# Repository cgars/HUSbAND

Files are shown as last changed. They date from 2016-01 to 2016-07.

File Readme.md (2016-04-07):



--
HUSbAND -  High freqUency StimulAtioN Device
-------------

Is a Ardoino micro based stimulation eyglass. It is used for high precission stimulation with light flickering at different frequencies.
This repsoitory contains (or will contain)
* The firmware for the arduino 
* The schemata for the eypieces and the controll board
* PCB Designs for the eypieces and the controll board

--
 Usage
-------------
The device can be used by wrtiting a command strings to the serial port emulated by the arduinos ftdi usb chip. A command consists of a upper case letter (R,G,B,I,F,H,S,X,T) and sometimes a number (R,G,B,I,F,H,T) that is either 8 bit unsigned integer (R,G,B,I) or 32 bit unsigned integer (F,H,T). Due to the way the device uses counters the Frequency the device produces will not match the frequency set exactly but it tries to come as close as possible.

Command Letter | Values | Function
------------ | -------------|-------------
R|0-1023|Red leds
G|0-1023|Green leds
B|0-1023|Blue leds
F|0-15kHZ|Frequency1
H|0-15kHz|Frequency2
T|0-99999|Time in ms between onset of freq1 and freq2
S||Start the Device
X||Stop the Device

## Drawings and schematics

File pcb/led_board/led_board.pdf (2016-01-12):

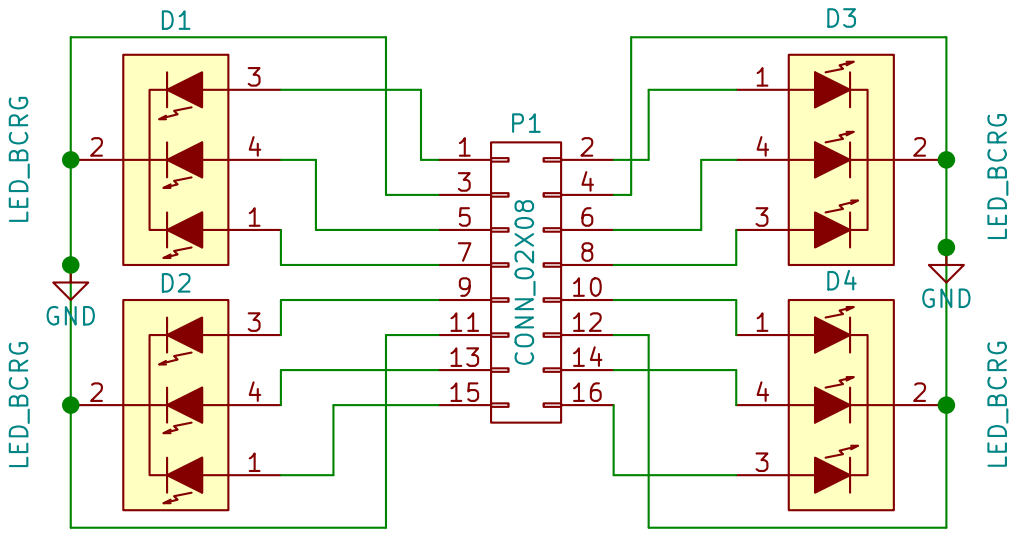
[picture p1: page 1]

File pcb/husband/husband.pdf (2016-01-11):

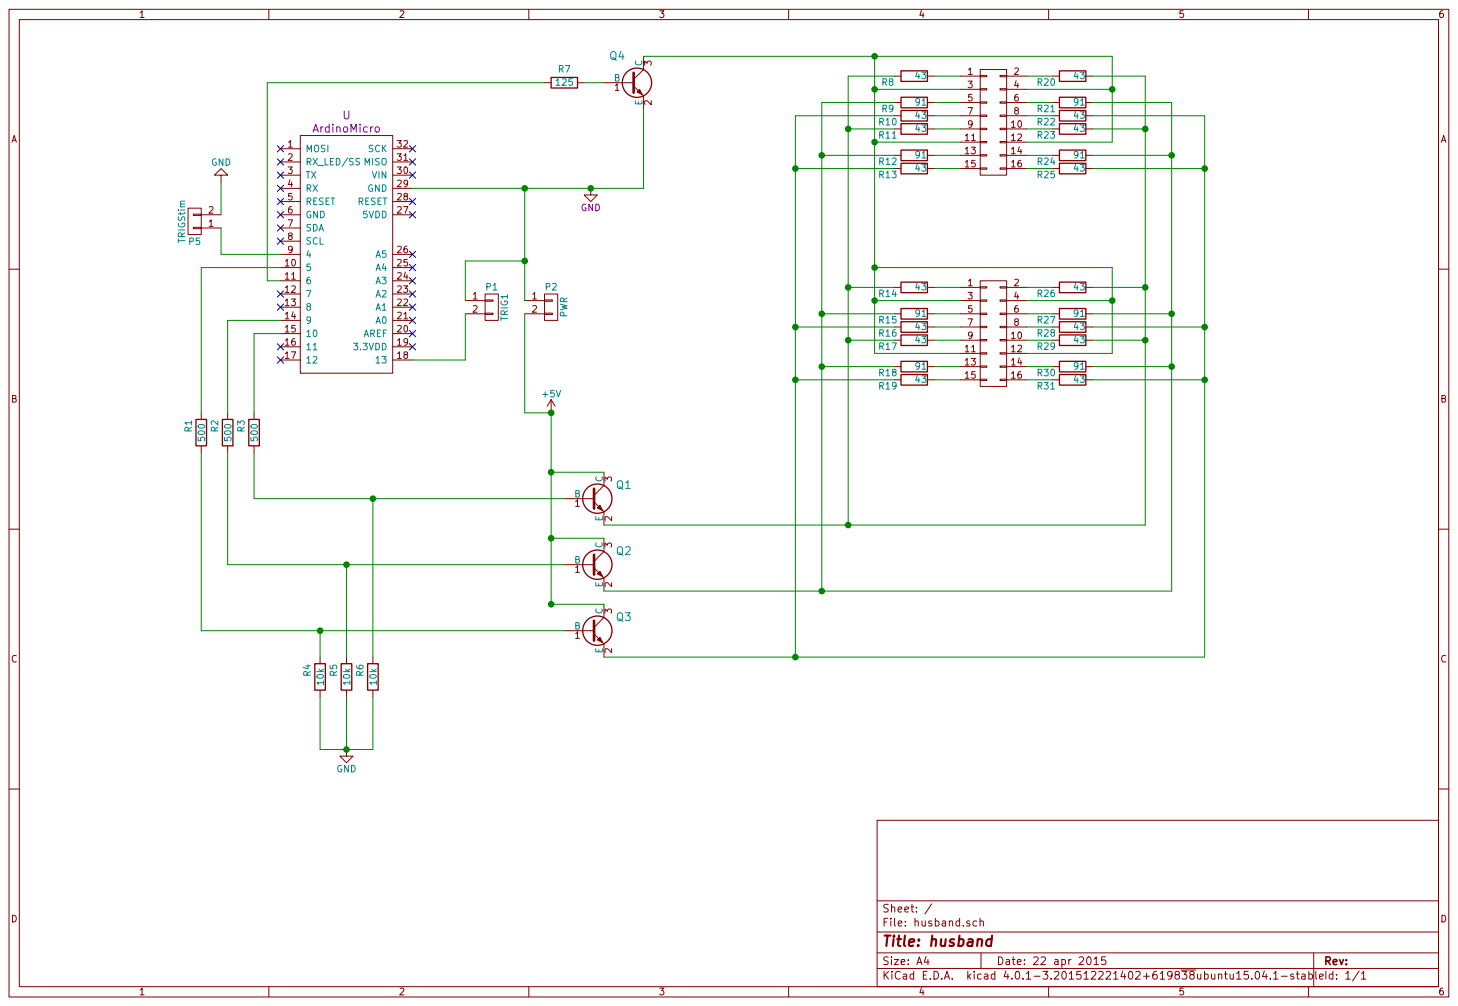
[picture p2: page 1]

File: husband.sch Sheet: /
Id: 1/1 Title: husband

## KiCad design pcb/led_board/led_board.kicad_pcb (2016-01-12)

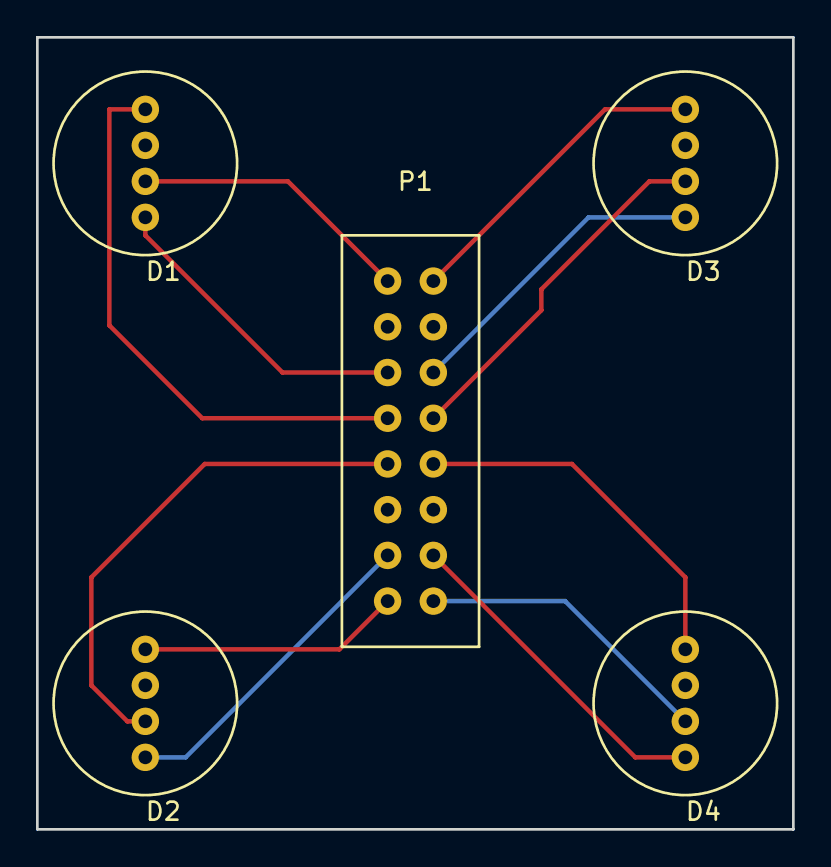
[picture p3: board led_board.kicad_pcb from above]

Board: 2 copper layers, 42.0 x 44.0 mm, 5 parts (0 on the bottom side), 13 nets.

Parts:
D1, D2, D3, D4: LED_BCRG; RGB_LED_BCRG
P1: CONN_02X08; Buchsenleiste

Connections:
GND: D1.2, D2.2, D3.2, D4.2, P1.3, P1.4, P1.11, P1.12
unnamed: D1.1, P1.7
unnamed: D1.3, P1.1
unnamed: D1.4, P1.5
unnamed: D2.1, P1.15
unnamed: D2.3, P1.9
unnamed: D2.4, P1.13
unnamed: D3.1, P1.2
unnamed: D3.3, P1.8
unnamed: D3.4, P1.6
unnamed: D4.1, P1.10
unnamed: D4.3, P1.16
unnamed: D4.4, P1.14

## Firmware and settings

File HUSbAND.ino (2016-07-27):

//-------------------------------------------------------------------------------
//
// HUSbAND 	  High freqUency StimulAtioN Device
// Copyright (c) 2015 Christian Garbers.
// All rights reserved. This program and the accompanying materials
// are made available under the terms of the Simplified BSD License
// which accompanies this distribution
//
// Contributors:
//     Christian Garbers - initial API and implementation
//-------------------------------------------------------------------------------

//The setup function is called once at startup of the sketch

#include <Arduino.h>
#include "wiring_private.h"
//#include <math.h>

const int RED_PIN = 10;
const int GREEN_PIN = 5;
const int BLUE_PIN = 9;
const int STIM_TRIG_PIN = 4;
const int FREQ_PIN = 6;
const double CLOCK = 16000000;
const int LED_TRIG_PIN = 13;

volatile uint16_t *GREENR = &OCR3A;
volatile uint16_t *REDR = &OCR1B;
volatile uint16_t *BLUER = &OCR1A;

uint16_t RED = 1023;
uint16_t GREEN = 1023;
uint16_t BLUE = 1023;
double INTENSITY = 1;
char SERIAL_BUFFER[10];
int FREQ=100;
char str_buf[10];
bool EXPERIMENT = false;
const double CARRIERFREQ = 16000000/1024;

double MAXFREQCOUNTS[2] = {(CARRIERFREQ/100)/2, (CARRIERFREQ/500)/2};//{31,62};
int MAXFREQINDEX = 0;
volatile unsigned long int FREQCOUNTER = 0;
volatile unsigned long int MAXFREQCOUNT = (CARRIERFREQ/500)/2;
volatile unsigned long int STIM_COUNTER = 0;
unsigned long int F_ONE_MAX = 15625;
unsigned int ISI;
unsigned long int NEWMAXFREQCOUNT;

unsigned char sreg;

uint8_t FREQ_BIT;
uint8_t FREQ_PORT;
volatile uint8_t *FREQ_OUT;

uint8_t LEDT_BIT;
uint8_t LEDT_PORT;
volatile uint8_t *LEDT_OUT;

uint8_t STIMT_BIT;
uint8_t STIMT_PORT;
volatile uint8_t *STIMT_OUT;


/* Interrupt Service Routines
 * The ISR of the timer with the highest pwm duty cycle is executed
 * each time a compare match interrupt has been triggered by the respective
 * Timer/Counter (see above for which T/C is which led). In case we increase
 * the FREQCOUNTER by one.
 * If FREQCOUNTER is above THE MAXFRECCOUNT the output Freq needs to be
 * changed
 *   After the toggle (and only then) we can also change the stimulation
 * frequency if a change is needed by updating the MAXFREQCOUNTER
 * Furthermore the triggers need to be toggled
 */
ISR(TIMER1_COMPB_vect){
	  FREQCOUNTER++;
	  STIM_COUNTER++;
	  if(FREQCOUNTER>MAXFREQCOUNT){
		  *FREQ_OUT ^= FREQ_BIT;
		  FREQCOUNTER=0;
		  if((STIM_COUNTER>F_ONE_MAX) && ((*FREQ_OUT)==FREQ_BIT) && EXPERIMENT){
			  MAXFREQINDEX=1;//in this setting the frequency switch happens just once
			  //MAXFREQINDEX^=1;
			  MAXFREQCOUNT = MAXFREQCOUNTS[MAXFREQINDEX];
			  STIM_COUNTER=0;
			  *LEDT_OUT ^= LEDT_BIT;
			  *STIMT_OUT ^= STIMT_BIT;
			  EXPERIMENT = false;
		  }
	  }
}
ISR(TIMER1_COMPA_vect){
	  FREQCOUNTER++;
	  STIM_COUNTER++;
	  if(FREQCOUNTER>MAXFREQCOUNT){
		  *FREQ_OUT ^= FREQ_BIT;
		  FREQCOUNTER=0;
		  if((STIM_COUNTER>F_ONE_MAX) && ((*FREQ_OUT)==FREQ_BIT) && EXPERIMENT){
			  MAXFREQINDEX=1;
			  //MAXFREQINDEX^=1;
			  MAXFREQCOUNT = MAXFREQCOUNTS[MAXFREQINDEX];
			  STIM_COUNTER = 0;
			  *LEDT_OUT ^= LEDT_BIT;
			  *STIMT_OUT ^= STIMT_BIT;
			  EXPERIMENT = false;
		  }
	  }
}
ISR(TIMER3_COMPA_vect){
	  FREQCOUNTER++;
	  STIM_COUNTER++;
	  if(FREQCOUNTER>MAXFREQCOUNT){
		  *FREQ_OUT ^= FREQ_BIT;
		  FREQCOUNTER=0;
		  if((STIM_COUNTER>F_ONE_MAX) && ((*FREQ_OUT)==FREQ_BIT) && EXPERIMENT){
			  MAXFREQINDEX=1;
			  //MAXFREQINDEX^=1;
			  MAXFREQCOUNT = MAXFREQCOUNTS[MAXFREQINDEX];
			  STIM_COUNTER = 0;
			  *LEDT_OUT ^= LEDT_BIT;
			  *STIMT_OUT ^= STIMT_BIT;
			  EXPERIMENT = false;
		  }
	  }
}


/**
 * This function controls the led flickering
 * buffer[0] is expected to be either R,G,B,I,F,H,S,X,T
 * fellowd by either some value (RGBIFT) or nothing
 * R,G,B: controls the duty cycle of either the Red,Green or Blue leds
 *  The duty cycle is a 10bit unsigned integer (0-1023)
 * F,H: are the two frequencies used on top of the 15kHz carrier frequency
 * S: Starts the experiment
 * X: Stops the experiment
 * T: controls the interstimulus interval-> the time between frequency switches
 */
int executecommand(char *buffer){
  //Serial.write(buffer);
	switch(buffer[0]){
		case 'R':
			RED = atoi(++buffer);
			if(RED == 0){
				cbi(TCCR1A, COM1B1);
				Serial.write("Red 0");
			}
			if(RED>BLUE and RED>GREEN) {
				/**
				* In case red is the maximum value this ensures that the
				* Interrupt Mask Register of the "RED" counter (TIMSK1) is
				* modified such that the Compare B Match interrupt is enabled.
				* This ensures that frequency changes to happen only after a
				* duty cycle is complete ensuring that frequency changes do not
				* interrupt duty cycles and thereby lead to a
				* hypothetical brightness changes.
				*/
				TIMSK1 = _BV(OCIE1B);
				TIMSK3 = 0 ;
			}
			*REDR = RED * INTENSITY;
			return 1;
		case 'G':
			GREEN = atoi(++buffer);
			if(GREEN == 0){
				Serial.write("Green 0");
				cbi(TCCR3A, COM3A1);
			}

			if(GREEN>BLUE and GREEN>RED) {
				TIMSK3 = _BV(OCIE3A);
				TIMSK1 = 0 ;
			}
			*GREENR = GREEN * INTENSITY ;
			return 1;
		case 'B':
			BLUE = atoi(++buffer);
			if(BLUE == 0){
				Serial.write("Blue 0");
				cbi(TCCR1A, COM1A1);
			}
			if(BLUE>GREEN and BLUE>RED) {
				TIMSK1 = _BV(OCIE1A);
				TIMSK3 = 0 ;
			}
			*BLUER = BLUE * INTENSITY;
			return 1;
		case 'I':
			INTENSITY = atof(++buffer);
			*GREENR = GREEN * INTENSITY ;
			*REDR = RED * INTENSITY;
			*BLUER = BLUE * INTENSITY;
			return 1;
		case 'F':
			FREQ = atoi(++buffer);
			NEWMAXFREQCOUNT = (CARRIERFREQ/FREQ)/2;
			digitalWrite(STIM_TRIG_PIN, !digitalRead(STIM_TRIG_PIN));
			dtostrf(NEWMAXFREQCOUNT,5,1,str_buf);
			Serial.write(str_buf);
			MAXFREQCOUNTS[0] = NEWMAXFREQCOUNT  ;
			MAXFREQCOUNT = MAXFREQCOUNTS[0];
			MAXFREQINDEX = 0;
			return 1;
		case 'H':
			FREQ = atoi(++buffer);
			NEWMAXFREQCOUNT = (CARRIERFREQ/FREQ)/2;
			digitalWrite(STIM_TRIG_PIN, !digitalRead(STIM_TRIG_PIN));
			//dtostrf(MAXFREQCOUNT,5,1,str_buf);
			//Serial.write(str_buf);
			MAXFREQCOUNTS[1] = NEWMAXFREQCOUNT  ;
			return 1;
		case 'S':
			if(!((*BLUER) == 0)) sbi(TCCR1A, COM1A1);
			if(!((*GREENR) == 0)) sbi(TCCR3A, COM3A1);
			if(!((*REDR) == 0)) sbi(TCCR1A, COM1B1);
			STIM_COUNTER = 0;
			EXPERIMENT = true;
			*LEDT_OUT ^= LEDT_BIT;
			*STIMT_OUT ^= STIMT_BIT;
			return 1;
		case 'X':
			cbi(TCCR1A, COM1A1);
			cbi(TCCR3A, COM3A1);
			cbi(TCCR1A, COM1B1);
			return 1;
		case 'T':
			ISI = atoi(++buffer);
			F_ONE_MAX = ISI*(CARRIERFREQ/1000.);
			dtostrf(F_ONE_MAX, 5, 1, str_buf);
			Serial.write(str_buf);
			return 1;
	}
	return 0;
}

/*
 * Read in data from Serial char by char
 * \n is ignored
 * \r triggers execution
 * Other characters are inserted into the buffer
 */
int readline(int readch, char *buffer, int len)
{
  static int pos = 0;
  int rpos;
  if (readch > 0) {
    switch (readch) {
      case '\n': \
        break;
      case '\r':
        rpos = pos;
        pos = 0;
        return executecommand(buffer);
      default:
        if (pos < len-1) {
          buffer[pos++] = readch;
          buffer[pos] = 0;
        }
    }
  }
  return -1;
}

void setup()
{
	  pinMode(RED_PIN, OUTPUT);
	  pinMode(GREEN_PIN, OUTPUT);
	  pinMode (BLUE_PIN, OUTPUT);

	  //Set counters 1 and 3 to Phase correct PWM 10 bit -> 15Khz and connect the OCR to pins
	  TCCR1A,TCCR1B,TCCR3A,TCCR3B  = 0;
	  TCCR1A = _BV (WGM10)|_BV(COM1A1)|_BV(COM1B1)| _BV(WGM11);
	  TCCR1B = _BV(CS10) | _BV(WGM12);
	  TCCR3A = _BV (WGM30)|_BV(COM3A1)|_BV(WGM31);
	  TCCR3B = _BV(CS30) | _BV(WGM32);

	  //Activate compare match Interupt for OCR1B (Red)
	  TIMSK1 = _BV(OCIE1B);

	  //Setup Counter4
	  pinMode(13, OUTPUT);
	  pinMode(6, OUTPUT);

	  sei();

	  Serial.begin(115200);

	  *GREENR = GREEN*INTENSITY ;
	  *REDR = RED*INTENSITY;
	  *BLUER = BLUE*INTENSITY;

	  FREQ_BIT = digitalPinToBitMask(FREQ_PIN);
	  FREQ_PORT = digitalPinToPort(FREQ_PIN);
	  FREQ_OUT = portOutputRegister(FREQ_PORT);

	  LEDT_BIT = digitalPinToBitMask(LED_TRIG_PIN);
	  LEDT_PORT = digitalPinToPort(LED_TRIG_PIN);
	  LEDT_OUT = portOutputRegister(LEDT_PORT);

	  STIMT_BIT = digitalPinToBitMask(STIM_TRIG_PIN);
	  STIMT_PORT = digitalPinToPort(STIM_TRIG_PIN);
	  STIMT_OUT = portOutputRegister(STIMT_PORT);
	  *STIMT_OUT ^= STIMT_BIT;

	  //leds off by default
	  cbi(TCCR1A, COM1A1);
	  cbi(TCCR3A, COM3A1);
	  cbi(TCCR1A, COM1B1);

	  }

void loop(){
	while(Serial.available()) readline(Serial.read(), SERIAL_BUFFER, 10);
	}

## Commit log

2015-03-06 Fixed wrong delay timing
    [HUSbAND.ino]
2015-03-06 printf no floats fix
    [HUSbAND.ino]
2015-03-10 write directly to the led trigger pin resisters
2015-03-11 LED trigger write directly again
2015-03-11 Clear OC resisters before writing
2015-03-26 no PWM on the main on/off pin anymore
2015-03-27 Clear PWM modes
2015-03-27 Set OCR4C as top for timer 4
2015-03-30 Fix: Set INTPIN to OUTPUT
    [HUSbAND.ino]
2015-03-30 Fix: green value is now read from input
    [HUSbAND.ino]
2015-03-31 Fix: Correct counting (added -1)
    [HUSbAND.ino]
2015-04-13 FIX: correct arduiono clock time (15mHz->16mHz)
    [HUSbAND.ino]
2015-04-21 Fix: Disconnect TC1 on 0 setting
    otherwise it is still high for 1 clock cycle
    [HUSbAND.ino]
2015-04-27 Switch to interuppt counting for Flicker generation
    To insure that led will only switch of after duty cycle end the flicker
    pin should only toggle when duty cycle is complete. this way it is
    ensured that stmuli will always have same intensity
2015-04-27 Switch on Timer1 interupts
2015-04-27 Fix: Get correct outregs for freq and trigger pin and Gui 0-255
    [HUSbAND.ino]
2015-04-28 Upgrade: intrerupt variable with max pwm channel
2015-05-04 Fix: missing carriage return in experiment control
    [HUSbAND.ino]
2015-05-05 Fix: Only change stimulation Frequency when cycle complete
    [HUSbAND.ino]
2015-05-05 FIX: Updated all ISR (not only one)
    [HUSbAND.ino]
2016-01-11 New: Added the mainboard pcb designs
    [husband.sch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]
2016-01-12 New: Added the led eyepeace pcb designs
    [led_board.kicad_pcb, led_board.sch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]
2016-03-22 Imp: Reprogram Device to test the frequenbcy transition
2016-04-07 Imp: Time till frequency switch can be larger than 2s
2016-04-11 Imp: Switch frequency on F command. Only change to H frequency after S
